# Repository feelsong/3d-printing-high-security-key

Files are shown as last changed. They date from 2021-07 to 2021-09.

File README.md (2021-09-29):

# 3D Printing Medeco M3 Biaxial Key
Medeco Key

Medeco M3 Key is a high security key with patented protection and biaxial cut design. Its design and key control makes the duplication of M3 keys virtually impossible through any locksmiths. Medeco locks are claimed to secure places across U.S governement and military installations.

## Key Control

Key Control is the system implemented by lock manufacturer to control the distribution, duplication, and privilege level of keys. The main purpose of key control is to make locks more secure by limiting the access to key blanks and restricting methods of key duplication. For Medeco M3, only authorized locksmiths with license are able to install and distribute Medeco M3 locks and keys.

## Pin Codes with Axial Cut

Axial Cuts

The M3 locks are pin tumbler locks with pins of various length with axial rotation to prevent from opening the cylinder. Each cut has a possiblity of 6 depths, 3 angles and 3 horizontal offsets. The vertical depth of the key will be measured from the root of the key. Angles are left, right and center with 20 degree angle used. If cuts looked from the shoulder are made in clock wise, they are right cuts. There are also 3 types of spacing(Fore, Center, Aft) to each cuts. While Fore cuts come before the center point, Aft cuts are cuts made away from center points for original pin space. The dimensions for spacing and depth are shown below.
<table class="tg">
  <tr>
    <th class="tg-0pky"></th>
    <th class="tg-0pky" colspan="2">1</th>
    <th class="tg-0pky" colspan="2">2</th>
    <th class="tg-0pky" colspan="2">3</th>
    <th class="tg-0pky" colspan="2">4</th>
    <th class="tg-0pky" colspan="2">5</th>
    <th class="tg-0pky" colspan="2">6</th>
  </tr>
  <tr>
    <td class="tg-0pky"></td>
    <td class="tg-0pky">F</td>
    <td class="tg-0pky">A</td>
    <td class="tg-0pky">F</td>
    <td class="tg-0pky">A</td>
    <td class="tg-0pky">F</td>
    <td class="tg-0pky">A</td>
    <td class="tg-0pky">F</td>
    <td class="tg-0pky">A</td>
    <td class="tg-0pky">F</td>
    <td class="tg-0pky">A</td>
    <td class="tg-0pky">F</td>
    <td class="tg-0pky">A</td>
  </tr>
  <tr>
    <td class="tg-0pky">Spacing</td>
    <td class="tg-0pky">0.213"</td>
    <td class="tg-0pky">0.275"</td>
    <td class="tg-0pky">0.383"</td>
    <td class="tg-0pky">0.445"</td>
    <td class="tg-0pky">0.553"</td>
    <td class="tg-0pky">0.615"</td>
    <td class="tg-0pky">0.723"</td>
    <td class="tg-0pky">0.785"</td>
    <td class="tg-0pky">0.893"</td>
    <td class="tg-0pky">0.955"</td>
    <td class="tg-0pky">1.063"</td>
    <td class="tg-0pky">1.125"</td>
  </tr>
  <tr>
    <td class="tg-0lax">Depth</td>
    <td class="tg-0lax" colspan="2">0.272"</td>
    <td class="tg-0lax" colspan="2">0.247"</td>
    <td class="tg-0lax" colspan="2">0.222"</td>
    <td class="tg-0lax" colspan="2">0.197"</td>
    <td class="tg-0lax" colspan="2">0.172"</td>
    <td class="tg-0lax" colspan="2">1.42"</td>
  </tr>
</table>

## Side

The precision cuts on the side of the key push slider into the correct alignment with the sidebar. The keyway of M3 key seems widely varied by key blanks. Due to the restrictive nature of key blanks, the layout for keyway is well documented. However, it is fairly simple to replicate.

## 3D Printed Key

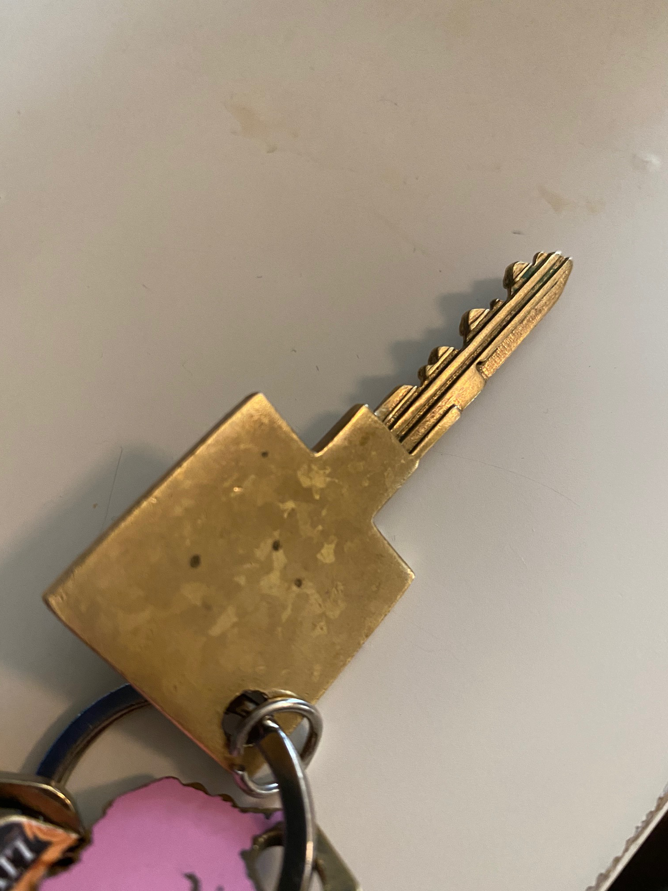
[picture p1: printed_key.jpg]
Printed Key

Polished Brass 

## OpenSCAD

[OpenSCAD](https://openscad.org/) is software for creating solid 3D CAD models. It is free software and available for Linux/UNIX, Windows and Mac OS X. Unlike most free software for creating 3D models (such as Blender) it does not focus on the artistic aspects of 3D modelling but instead on the CAD aspects. Thus it might be the application you are looking for when you are planning to create 3D models of machine parts but pretty sure is not what you are looking for when you are more interested in creating computer-animated movies.

## Reference
* [http://www.3ders.org/articles/20111031-duplicate-your-keys-with-a-3d-printer.html](http://www.3ders.org/articles/20111031-duplicate-your-keys-with-a-3d-printer.html)
* [https://www.forbes.com/sites/andygreenberg/2012/07/16/hacker-opens-high-security-handcuffs-with-3d-printed-and-laser-cut-keys/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](https://www.forbes.com/sites/andygreenberg/2012/07/16/hacker-opens-high-security-handcuffs-with-3d-printed-and-laser-cut-keys/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)
* [https://www.wired.com/2008/08/medeco-locks-cr/](https://www.wired.com/2008/08/medeco-locks-cr/)
* [https://www.youtube.com/watch?v=iOIRZnafgQk](https://www.youtube.com/watch?v=iOIRZnafgQk)
* [https://www.geek.com/chips/cheap-3d-printed-plastic-key-can-open-most-locks-1603073/](https://www.geek.com/chips/cheap-3d-printed-plastic-key-can-open-most-locks-1603073/)
* [http://reedbrotherssecurity.com/medeco-m3-biaxial/](http://reedbrotherssecurity.com/medeco-m3-biaxial/)
* [https://hackaday.com/2017/12/18/3d-printed-key-saves-the-day/](https://hackaday.com/2017/12/18/3d-printed-key-saves-the-day/)
* [http://lockwiki.com/index.php/Medeco_M3](http://lockwiki.com/index.php/Medeco_M3)
* [https://www.youtube.com/watch?v=FDcyqHvAt3Y](https://www.youtube.com/watch?v=FDcyqHvAt3Y)
* [https://www.thingiverse.com/thing:1819242](https://www.thingiverse.com/thing:1819242)
* [https://www.youtube.com/watch?v=l32mOvnT_ls](https://www.youtube.com/watch?v=l32mOvnT_ls)
* [https://hackaday.com/2015/05/23/pictures-that-defeat-key-locks/](https://hackaday.com/2015/05/23/pictures-that-defeat-key-locks)
* [https://www.wired.com/2015/08/this-app-lets-anyone-3-d-print-do-not-duplicate-keys/](https://www.wired.com/2015/08/this-app-lets-anyone-3-d-print-do-not-duplicate-keys)
* [http://www.instructables.com/id/3D-Print-a-Fully-Functional-Key/](http://www.instructables.com/id/3D-Print-a-Fully-Functional-Key)
* [http://web.archive.org/web/20050217020917fw_/http://dlaco.com/spacing/tips.htm](http://web.archive.org/web/20050217020917fw_/http://dlaco.com/spacing/tips.htm])
* [http://theamazingking.com/images/locks/m3/m3.html](http://theamazingking.com/images/locks/m3/m3.html)
* [http://www.locksafesystems.com/depth_and_space.htm#Medeco_Biaxial_M3_Space_and_Depth](http://www.locksafesystems.com/depth_and_space.htm#Medeco_Biaxial_M3_Space_and_Depth)
* [https://books.google.com/books?id=7m41LA8WsvUC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](https://books.google.com/books?id=7m41LA8WsvUC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)

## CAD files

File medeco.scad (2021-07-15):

$fn=100;

// This converts inches to millimeters
function mm(i) = i*25.4;

// The handle of the key. Doesn't do much aside from help turn the key.
module bow(bow_length, bow_width, bow_thickness)
{
	// Creates the hole in the "box"
	difference() {
		// Creates the big "box"
		cube([bow_length, bow_width, bow_thickness]);
		// Cuts out the round hole in it
		translate([mm(0.2), mm(0.2), 0]) cylinder(mm(.5), mm(.1));
  }
}

// A single bit ( I think )
module bit()
{
	w = mm(.15);
	difference()
	{
		translate([-(mm(1/4))/2, 0, -(mm(1/4))/2]) cube([mm(1/4), mm(1), 2*w]);
		translate([-mm(4/512)+0.007, 0, -w]) rotate([0, 0, 133]) cube([w*2, w*2, 3*w]);
		translate([mm(4/512)-0.008, 0, -w]) rotate([0, 0, -43]) cube([w, w*2, 3*w]);
	}
}

// Calculates most things for the blade
module blade(blade_length, blade_width, blade_thickness, key_cuts, key_cut_angle, key_cut_spacing, shoulder, cut_spacing, cut_depth)
{
	// The first item in this is the starting block. All subsequent items get subtracted from the first one.
	difference()
	{
		// Makes the blade, basically a squared off rectangle at this point.
		// Also has the groove for the (slider?).
		union() {
			translate([0, -0.4, 0]) cube([shoulder, mm(3/8) +0.4 , mm(.125)]);
			cube([blade_length + shoulder, blade_width, blade_thickness]);
		}
		
		// This cuts out part of the blade's tip top part to make it slanted.
		translate([blade_length + shoulder, mm(1/8), 0]) { rotate([0, 0, 43]) cube([10, 10, blade_thickness]); }
		// This cuts out part of the blade's tip bottom part to make it slanted.
		translate([blade_length + shoulder, mm(1/16), 0]) { rotate([0, 0, 220]) cube([10, 10, blade_thickness]); }
		
		//Side mill
		// - The eagle side
		// These control how deep the grooves go.
		// "Tip: The end of the key opposite of the bow. Some locks use the tip of the key to align cuts instead of the shoulder." http://www.lockwiki.com/index.php/Key
		tip = 0.8;
		tip2 = 0.3;
		tip3 = 0.4;
		
		// (left side is relative from looking at the key from the perspective of the lock)
		// These three cut out grooves on the side of the key on the left side
		translate([shoulder, 3.0988 , blade_thickness - tip]) cube([blade_length + 0.2, 0.7022, 1]);
		translate([shoulder, 5.0038 , blade_thickness - tip]) cube([blade_length + 0.2, 0.6604, 1]);
		// This one is for the top part.
		translate([shoulder, 6.1468 , blade_thickness - tip2]) cube([blade_length + 0.2, 1.65, 1]);
		
		
		// - The Non-eagle side
		// (right side is relative from looking at the key from the perspective of the lock)
		// These ones are for right side of the key.
		translate([shoulder, 0.7366, tip - 1]) cube([blade_length + 0.2, 1 , 1]);
		translate([shoulder, 2.9464, tip - 1]) cube([blade_length + 0.2, 1 , 1]);
		translate([shoulder, 4.8514, tip - 1]) cube([blade_length + 0.2, 0.9, 1]);
		translate([shoulder, 6.9342, tip3 - 1]) cube([blade_length + 0.2, 0.7366, 1]);

		// Cuts the bits in the blade. Also does the biaxial rotation.
		for (counter = [0:5])
		{
			translate([ shoulder + mm(0.244) + cut_spacing*counter + key_cut_spacing[counter] * mm(0.031), blade_width - (key_cuts[counter]) * cut_depth + 0.000125, blade_thickness/2])
			rotate ([0, key_cut_angle[counter] * 20, 0])
			bit();
		}
	}
}


module biaxial(key_cuts, key_cut_angle, key_cut_spacing)
{   
	blade_length = mm(1.3125);
	blade_width = mm(0.296875);
	blade_thickness = mm(0.09375);

	// The shoulder is the part of the key that connects to the bow of the blade.
	shoulder = mm(0.3125);
	cut_spacing = mm(.17);
	cut_depth = mm(.025);

	bow_length = mm(1.09375);
	bow_width = mm(1.09375);
	bow_thickness = mm(.125);
	
	//from origin to the bottom of the blade
	blade_starting = 11;
	
	//first difference on eagle side
	dip = 2.1336;

	difference()
	{
		union()
		{
			// Draw the bow
			bow(bow_length, bow_width, bow_thickness);
			translate([bow_length, bow_width - blade_width - blade_starting, 0])
			
			// Draw the blade
			blade(blade_length, blade_width, blade_thickness, key_cuts, key_cut_angle, key_cut_spacing, shoulder, cut_spacing, cut_depth);
			translate([mm(1.09375 + 0.3125), bow_width - blade_width - blade_starting, mm(0.09375)]) cube([mm(0.3125), mm(0.0625), mm(0.03125)]);
		}

		translate([mm(1.921875), bow_width - blade_width - blade_starting - 0.5 ,mm(0.0625)]) cube([mm(0.796875) + 0.5, dip + 0.5, mm(0.3125) + 0.5]);
		translate([mm(1.921875) +mm(0.02) , bow_width - blade_width - 11 + mm(0.08)  , mm(0.0625)]) cylinder(mm(0.5), mm(0.0234375));
	}
}

// See this page to understand all of the lingo about fore / aft
// http://www.lockwiki.com/index.php/Medeco_Biaxial

//Angles:
//     -1 = -20
//      0 = 0
//      1 = 20


//Cut spacing:
//      aft = -1
//      center = 0
//      fore = 1


// Current pin
// These are ordered by cuts closest to the bow first.
//           Key Cuts          Key Cut Angle       Key Cut Spacing
biaxial([3, 2, 4, 3, 4, 3], [0, 1, 1, 1, 1, 0], [1, -1, -1, 1, -1, 1]);



// The original function call that came with this scad model:
// biaxial([3, 2, 4, 3, 4, 3], [0, 1, 1, 1, 1, 0], [1, -1, -1, 1, -1, 1]);

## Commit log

2018-06-01 Initial File
    [medeco.scad]
2018-06-05 Sidebar Difference
    [medeco.scad]
2018-06-06 Proper Rotation Axis
    [medeco.scad]
2018-06-15 side mill + clean up[
    [medeco.scad]
2018-06-17 Cylinder Offset
    [medeco.scad]
2018-06-18 Add Rounded Cube For Side Milling
    [medeco.scad]
2018-06-26 Regular Cube Cuts
    [medeco.scad]
2020-10-10 Made comments
    [medeco.scad]
2020-10-11 Update medeco.scad
    Formatting
    [medeco.scad]
2021-09-27 printed key
